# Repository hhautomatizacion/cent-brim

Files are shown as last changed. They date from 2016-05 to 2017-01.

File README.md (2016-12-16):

<br/>
<p align="center">
  
</p>
<br/>

# cent-brim

## Fecha
* 2004

## Descripcion del proyecto
* Modificacion de centrifuga brim para trabajar con motor electrico en lugar de motor hidraulico.

## Herramientas utilizadas
* Ninguna

## Modelos de PLC, etc.
* Variador yaskawa

## Autores
* <a href="http://www.github.com/pedrohermon">pedrohermon</a> 
* <a href="http://www.github.com/genarohh">genarohh</a> 

## Comentarios
* Ninguno

## Contenido
* Carpeta de Diagramas
	* Diagramas del proyecto
		* Diagramas electricos
		* Diagramas de bloques
		* Dibujos
* Carpeta de Documentos
	* Documentos pensados para el usuario final
		* Manuales de usuario
		* Manuales de programacion
* Carpeta de Fotos
	* Fotos del proyecto antes, durante y despues del desarrollo del mismo
		* Fotos
		* Capturas de pantalla
* Carpeta de Historial
	* Documentacion del desarrollo del proyecto
		* Hojas de datos de componentes
		* Manuales de usuario de componentes
		* Documentacion de funciones, herramientas
* Carpeta de Programas
	* Programas de Computadora, PLC, etc. 
		* Codigos fuente
		* Iconos, imagenes usados en los programas
		* Archivos de configuracion de los programas
		* Programas compilados
* Carpeta de Pruebas
	* Pruebas preliminares del proyecto
		* Programas incompletos, o secciones de programas
		* Capturas de comunicacion
		* Modelos de componentes que se hayan probado

---
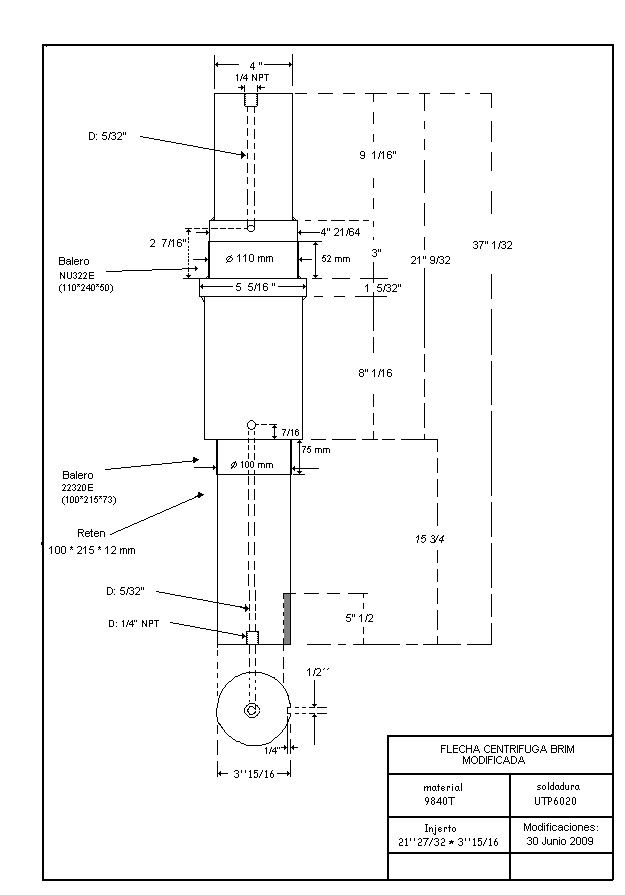
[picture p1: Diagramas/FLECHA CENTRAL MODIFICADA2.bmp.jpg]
FLECHA CENTRAL MODIFICADA2.bmp.jpg

---
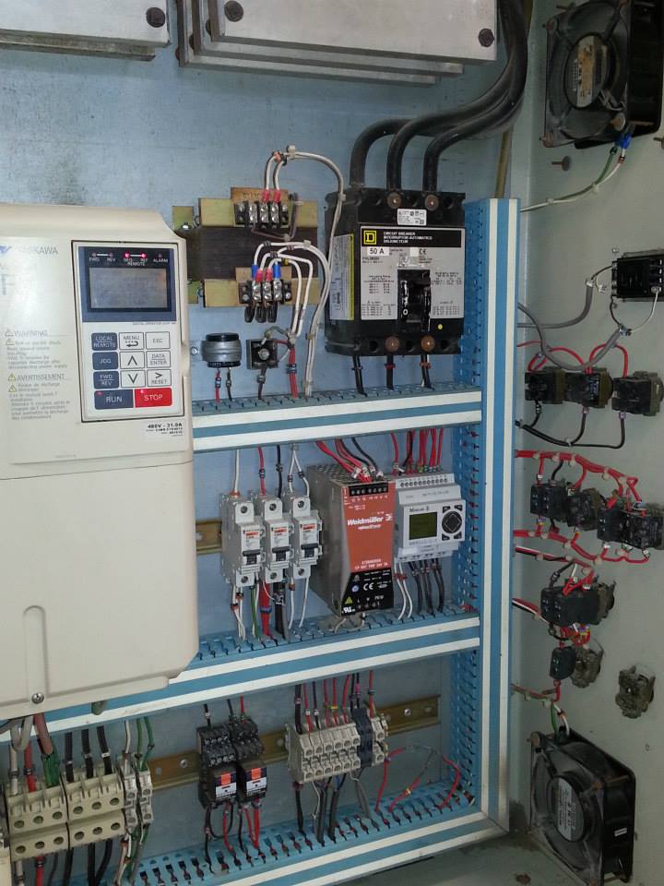
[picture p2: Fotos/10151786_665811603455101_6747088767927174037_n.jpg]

---
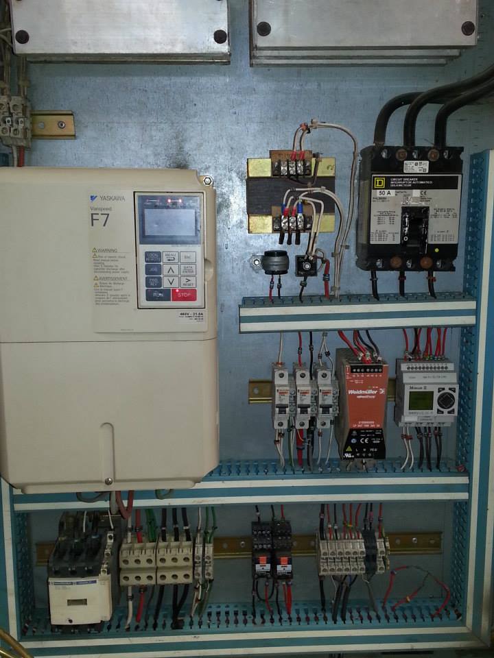
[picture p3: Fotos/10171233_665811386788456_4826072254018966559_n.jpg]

---

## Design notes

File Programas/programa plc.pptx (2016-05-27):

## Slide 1

PROGRAMA DE PLC EASY DE CENTRIFUGA BRIM

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
NOTA: La salida Q1 se conecta al cable no. 22 y 23
La salida Q2 se conecta al cable no. 15 y 71
La salida Q3 se conecta al cable no. 15 y 72
La salida Q4 se conecta al cable no. 15 y 73
VEASE EL DIAGRAMA DE CONTROL

M6

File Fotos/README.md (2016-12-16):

<br/>
<p align="center">
  
</p>
<br/>

# Carpeta de Fotos

## Fotos del proyecto antes, durante y despues del desarrollo del mismo

* Fotos

* Capturas de pantalla

---

---

---

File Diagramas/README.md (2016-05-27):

<br/>
<p align="center">
  
</p>
<br/>

# Carpeta de Diagramas

## Diagramas del proyecto

* Diagramas electricos

* Diagramas de bloques

* Dibujos

---
FLECHA CENTRAL MODIFICADA2.bmp.jpg
---

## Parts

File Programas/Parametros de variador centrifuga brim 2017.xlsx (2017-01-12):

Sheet: Param Cent F7
PARAMETROS PARA VARIADOR DE VELOCIDAD YASKAWA.
MODELO: CIMR-F7U4015
APLICACCION: CENTRIFUGA BRIM
NOTAS:
Para programar, situarse en el menu ( programacion ) y seguir estos pasos!
Opcional, ajustar idioma parametro A1-00 ( Selección de idioma )
Si el equipo es nuevo, aplicar parametros de la siguiente lista, ecepto parametro A1-03 ( Inicializar parametros ).
Si el equipo es usado, Aplicar el parametro A1-03 ( Inicializar parametros ) con la opcion 2220 ( Inicializar en 2 hilos )
Despues ajustar parametros de la siguiente lista, ecepto parametro A1-03 ( Inicializar parametros ).
Codigo | Descripcion | Valor | Descripcion
Parametro | Parametro | Ajustado | Ajuste
A1-00 | Selección de idioma | 5 | Español
A1-01 | Nivel de programacion | 2 | Nivel avanzado
A1-02 | Seleccion el metrodo de control | 2 | Vector abierto
A1-03 | Inicializar parameros (carga parametros de fabrica ) | 2220 | Dos hilos
B1-01 | Selección frecuencia de referencia | 0 | Por operador
C1-01 | Tiempo de aceleracion 1 | 230 | Segundos
C1-02 | Tiempo de desaceleracion 1 | 240 | Segundos
D1-01 | Frecuencia de referencia 1 | 27 | Hertz
D1-03 | Frecuencia de referencia 3 | 55 | Hertz
E1-01 | Voltaje de entrada a inversor | 440 | Volts AC
E1-05 | Voltaje maximo de salida | 440 | Volts AC
E1-08 | Tensión de la frecuencia de salida media | 24.2 | Volts AC
E1-10 | Tensión de la frecuencia de salida mínima | 4.4 | Volts AC
E1-13 | Voltaje base | 440 | Volts AC
E2-01 | Amperes de placa de motor | 19.5 | Amperes
E2-02 | Deslizamiento nominal del motor | 0.81 | Hertz
E2-03 | Amperes de motor sin carga | 8.6 | Amperes
E2-05 | Resistencia linia a linia de motor | 0.76 | Ohms
E2-06 | Inductancia de fuga del motor | 23.6 | Porcentaje
E2-07 | Coeficiente de saturación con núcleo de hierro 1 | 0.43 | Porcentaje
E2-08 | Coeficiente de saturación con núcleo de hierro 2 | 0.68 | Porcentaje
E2-11 | Potencia de motor | 11.19 | Kilowatts
E2-12 | Coeficiente de saturación con núcleo de hierro 3 | 1.6 | Porcentaje
H1-03 | Selección de funcion de terminal S5 | 4 | Referencia de multivelocidad 2
H1-04 | Selección de funcion de terminal S6 | 3 | Referencia de multivelocidad 3
H6-07 | Escala del monitor del tren de pulsos | 570 | Hertz
L1-01 | Selección de protección contra sobrecarga motor | 2 | Hertz
L3-04 | Selección prevencion de bloqueo durante la desaceleracion | 0 | Desactivada
L8-05 | Selección de protección contra pérdida de fase de entrada | 0 | Segundos
L8-09 | Selección de detección de falla de tierra en la salida | 0 | Desactivada
L8-10 | Selección de operación del ventilador de refrigeracion | 1 | Siempre
L8-12 | Configuración de la temperatura ambiente | 55 | Grados centigrados
 |  |  | 2017-01-01

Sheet: Param Cent A1000
PARAMETROS PARA VARIADOR DE VELOCIDAD YASKAWA.
MODELO: CIMR-AU4A0044FAA
APLICACCION: CENTRIFUGA BRIM
NOTAS:
Para programar, situarse en el menu ( programacion ) y seguir estos pasos!
Opcional, ajustar idioma parametro A1-00 ( Selección de idioma )
Si el equipo es nuevo, aplicar parametros de la siguiente lista, ecepto parametro A1-03 ( Inicializar parametros ).
Si el equipo es usado, Aplicar el parametro A1-03 ( Inicializar parametros ) con la opcion 2220 ( Inicializar en 2 hilos )
Despues ajustar parametros de la siguiente lista, ecepto parametro A1-03 ( Inicializar parametros ).
Codigo | Descripcion | Valor | Descripcion
Parametro | Parametro | Ajustado | Ajuste
A1-00 | Selección de idioma | 5 | Español
A1-01 | Nivel de programacion | 2 | Nivel avanzado
A1-02 | Seleccion el metrodo de control | 2 | Vector abierto
A1-03 | Inicializar parameros (carga parametros de fabrica ) | 2220 | Dos hilos
B1-01 | Selección frecuencia de referencia | 0 | Por operador
C1-01 | Tiempo de aceleracion 1 | 230 | Segundos
C1-02 | Tiempo de desaceleracion 1 | 270 | Segundos
D1-01 | Frecuencia de referencia 1 | 27 | Hertz
D1-03 | Frecuencia de referencia 3 | 55 | Hertz
E1-01 | Voltaje de entrada a inversor | 440 | Volts AC
E1-04 | Frecuencia maxima de salida | 80 | Hertz
E1-05 | Voltaje maximo | 440 | Volts AC
E1-13 | Voltaje base | 440 | Volts AC
E2-01 | Amperes de placa de motor | 19.5 | Amperes
E2-02 | Deslizamiento nominal del motor | 0.81 | Hertz
E2-03 | Amperes de motor sin carga | 8.6 | Amperes
E2-05 | Resistencia linia a linia de motor | 0.76 | Ohms
E2-11 | Potencia de motor | 11.19 | Kilowatts
H1-05 | Selección de funcion de terminal S5 | 4 | Referencia de multivelocidad 2
H1-06 | Selección de funcion de terminal S6 | 5 | Referencia de multivelocidad 3
H6-07 | Escala del monitor del tren de pulsos | 570 | Hertz
L3-01 | Selección prevencion de bloqueo durante la aceleracion | 0 | Desactivada
L3-04 | Selección prevencion de bloqueo durante la desaceleracion | 0 | Desactivada
L3-24 | Tiempo de aceleración del motor para calcular la inercia | 0.265 | Segundos
L8-10 | Selección de operación del ventilador de refrigeracion | 1 | Siempre
 |  |  | 2017-01-01

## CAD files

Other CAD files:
Diagramas/Diagrama Centrifuga Brim 2017.dwg
Diagramas/flecha motor 15 hp.dwg
Diagramas/ALTURA DE PIERNA1.dwg
Diagramas/Buje de centrifuga mod.dwg
Diagramas/FLECHA DE PIERNA DE CENTRIFUGA.dwg
Diagramas/Amortiguador Original.dwg
Diagramas/CAJA DE PIERNA.dwg

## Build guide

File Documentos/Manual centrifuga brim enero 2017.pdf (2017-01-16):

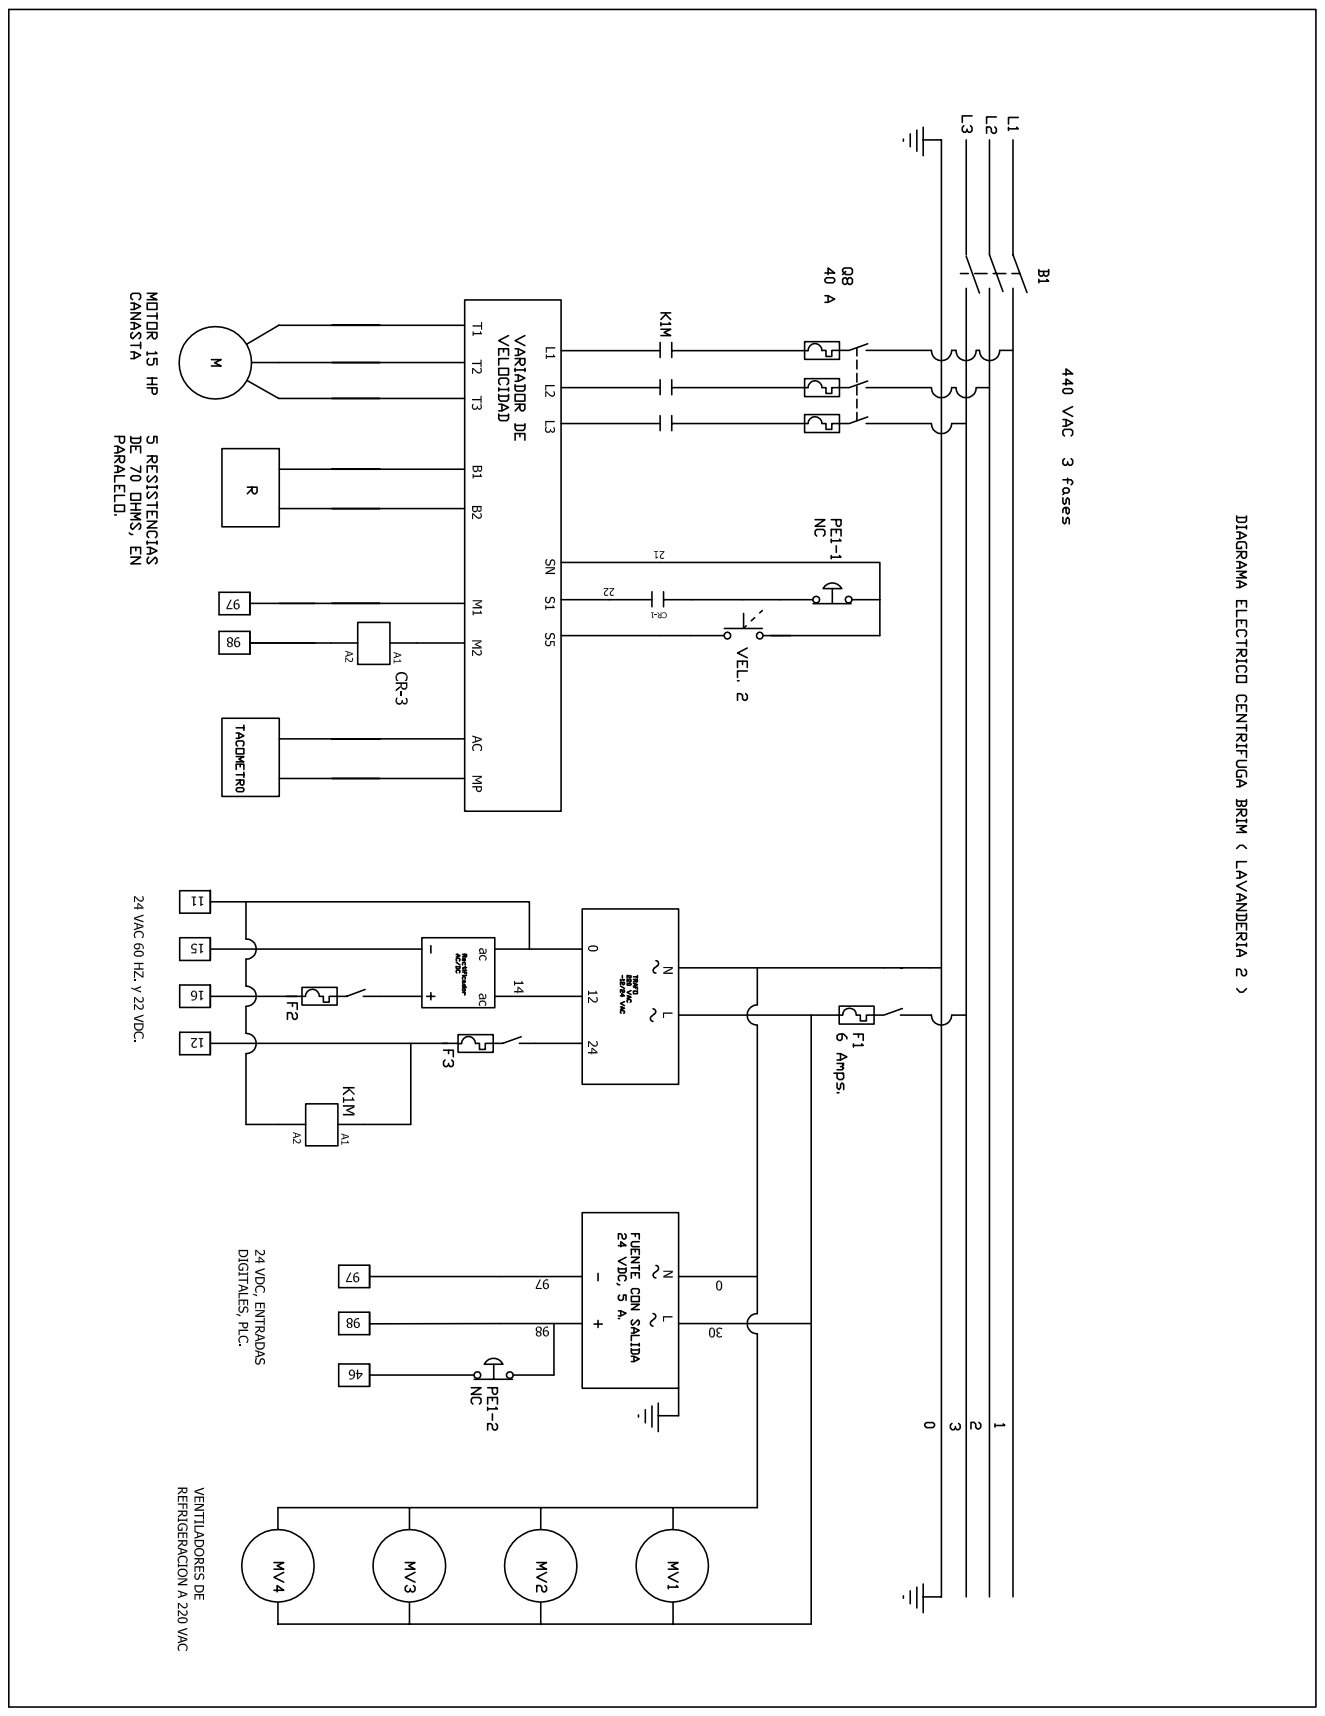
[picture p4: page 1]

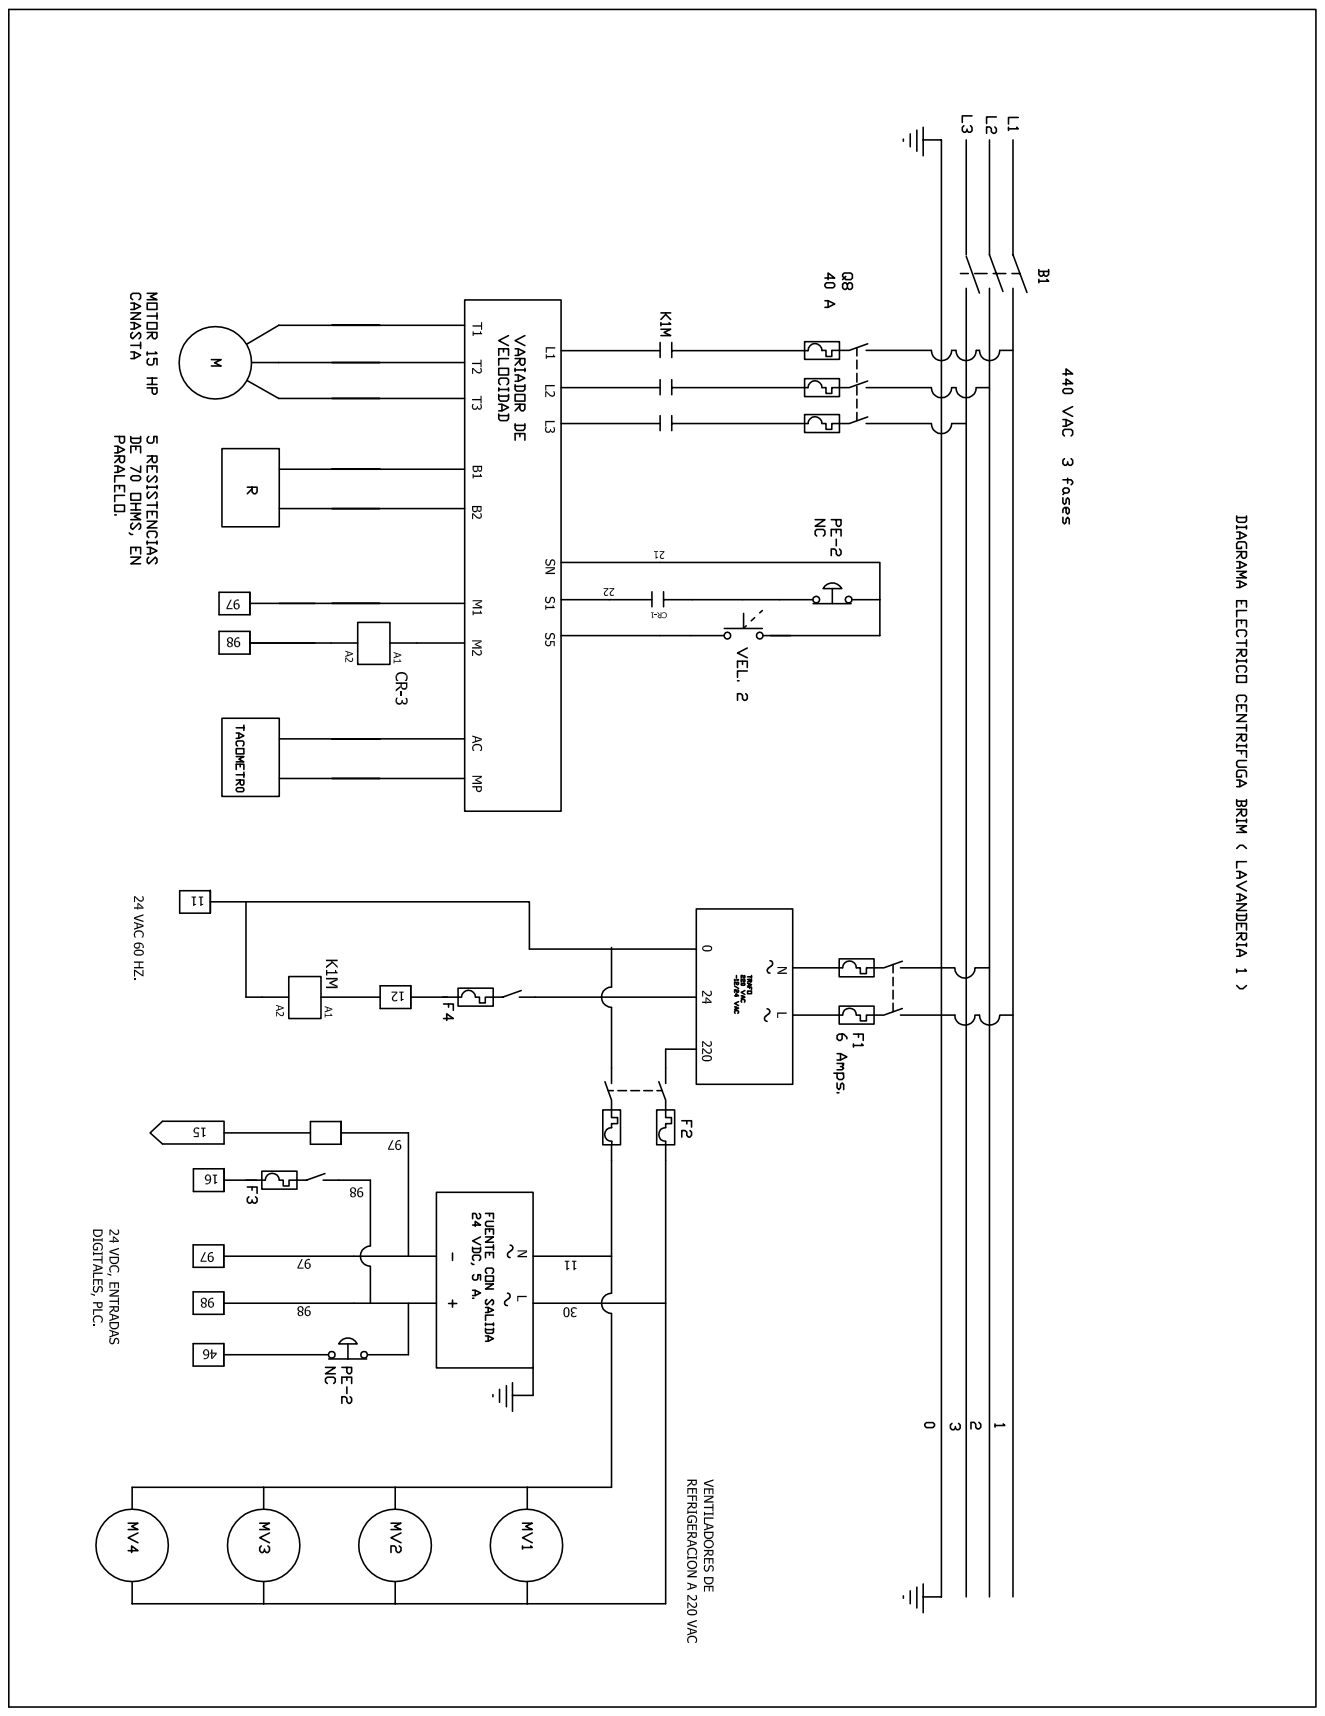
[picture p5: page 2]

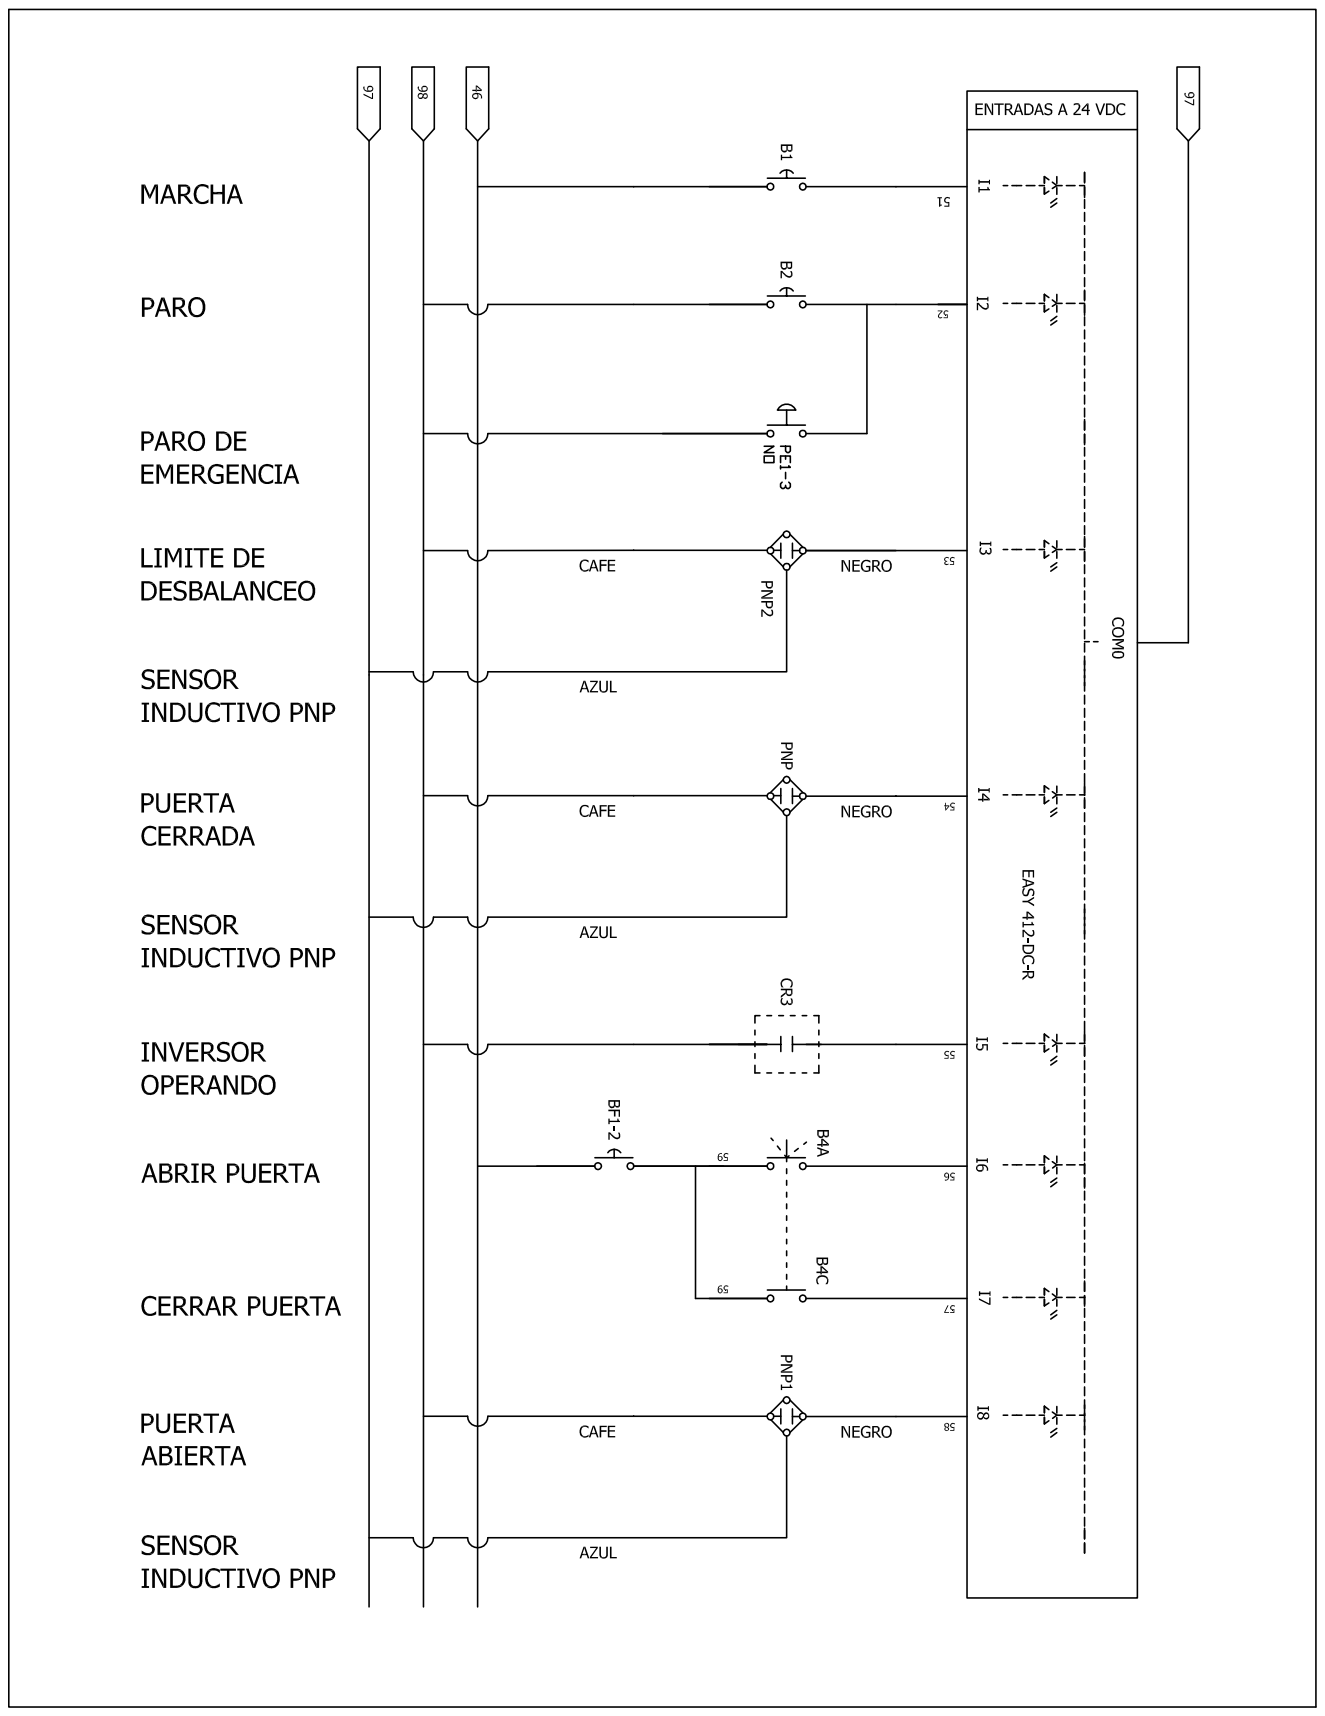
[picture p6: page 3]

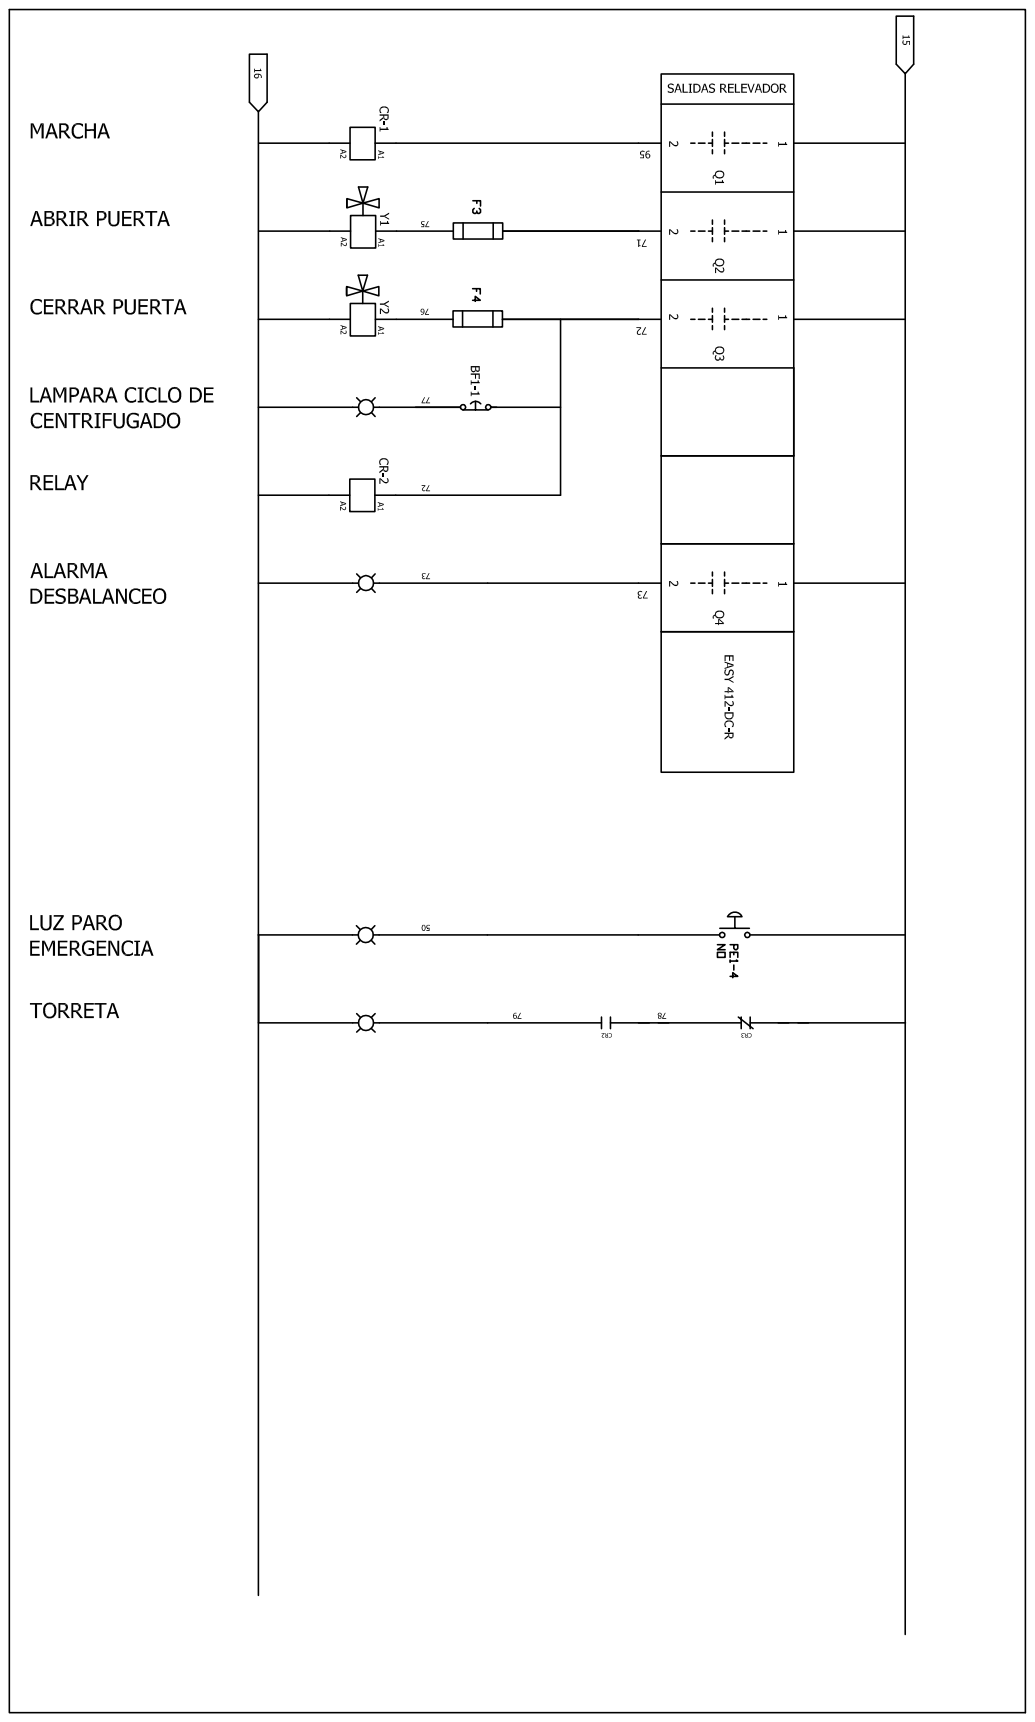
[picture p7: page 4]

### PROGRAMA DE PLC EASY DE CENTRIFUGA BRIM CLAVE DE ACCESO PLC: 0846

M2---M6---I4---{M1 | ;Subrutina de seguridad puerta cerrada.
M1---I1---M8---{M7 | ;subrutina de marcha
--------M7

## M7---M2---------{TT1

## I5-----I3-----I5---{M2 ;subrutina de desbalanceo y reset

M2-----------I2--

## M7-----------------{TT2

M3--
M2---------I6------{M3 | ;subrutina de seguridad, mantener puerta cerrada
M7-- | durante operación.
I5------I6----T2—{M6 | ;subrutina de finalización de ciclo.
M6

## M1---I2-------I5---{M4 ;subrutina de paro y paro de emergencia

M4-

## M7---I4-----M2---{M5

## M5---M4----T1----{Q1 ;subrutina para salida 1, activación de variador

M3

## ---------------{Q3 ;subrutina para salida 3, cerrar puerta

I7

M2-------------------{Q4 | ;subrutina para salida 4, alarma de desbalanceo
I6-----M2----M7---{Q2 | ;subrutina para salida 2, abrir puerta

## I8------I7-----Q1—

## I5------I4------------{M8

M8—

PARAMETROS TEMPORIZADOR 1: 6 MINUTOS, 38 SEGUNDOS.

X 00:00

M: S | 06:38
TRG | T1

## RES

PARAMETROS TEMPORIZADOR 2: 5 SEGUNDOS.

X----- | 00:00
M: S | 00:05
TRG | T2

## RES

### ENERO 2017

PARAMETROS PARA VARIADOR DE VELOCIDAD YASKAWA.

### MODELO: CIMR-F7U4015 APLICACCION: CENTRIFUGA BRIM

### NOTAS:

Para programar, situarse en el menu ( programacion ) y seguir estos pasos!
Opcional, ajustar idioma parametro A1-00 ( Selección de idioma )
Si el equipo es nuevo, aplicar parametros de la siguiente lista, ecepto parametro A1-03 ( Inicializar parametros ).
Si el equipo es usado, Aplicar el parametro A1-03 ( Inicializar parametros ) con la opcion 2220 ( Inicializar en 2 hilos ) Despues ajustar parametros de la siguiente lista, ecepto parametro A1-03 ( Inicializar parametros ).
Codigo | Descripcion | Valor | Descripcion
Parametro | Parametro | Ajustado | Ajuste
A1-00 | Selección de idioma | 5 | Español
A1-01 | Nivel de programacion | 2 | Nivel avanzado
A1-02 | Seleccion el metrodo de control | 2 | Vector abierto
A1-03 | Inicializar parameros (carga parametros de fabrica ) | 2220 | Dos hilos
B1-01 | Selección frecuencia de referencia | 0 | Por operador
C1-01 | Tiempo de aceleracion 1 | 230 | Segundos
C1-02 | Tiempo de desaceleracion 1 | 240 | Segundos
D1-01 | Frecuencia de referencia 1 | 27 | Hertz
D1-03 | Frecuencia de referencia 3 | 55 | Hertz
E1-01 | Voltaje de entrada a inversor | 440 | Volts AC
E1-05 | Voltaje maximo de salida | 440 | Volts AC
E1-08 | Tensión de la frecuencia de salida media | 24.2 | Volts AC
E1-10 | Tensión de la frecuencia de salida mínima | 4.4 | Volts AC
E1-13 | Voltaje base | 440 | Volts AC
E2-01 | Amperes de placa de motor | 19.5 | Amperes
E2-02 | Deslizamiento nominal del motor | 0.81 | Hertz
E2-03 | Amperes de motor sin carga | 8.6 | Amperes
E2-05 | Resistencia linia a linia de motor | 0.76 | Ohms
E2-06 | Inductancia de fuga del motor | 23.6 | Porcentaje
E2-07 | Coeficiente de saturación con núcleo de hierro 1 | 0.43 | Porcentaje
E2-08 | Coeficiente de saturación con núcleo de hierro 2 | 0.68 | Porcentaje
E2-11 | Potencia de motor | 11.19 | Kilowatts
E2-12 | Coeficiente de saturación con núcleo de hierro 3 | 1.6 | Porcentaje
H1-03 | Selección de funcion de terminal S5 | 4 | Referencia de multivelocidad 2
H1-04 | Selección de funcion de terminal S6 | 3 | Referencia de multivelocidad 3
H6-07 | Escala del monitor del tren de pulsos | 570 | Hertz
L1-01 | Selección de protección contra sobrecarga motor | 2 | Hertz
L3-04 | Selección prevencion de bloqueo durante la desaceleracion | 0 | Desactivada
L8-05 | Selección de protección contra pérdida de fase de entrada | 0 | Segundos
L8-09 | Selección de detección de falla de tierra en la salida | 0 | Desactivada
L8-10 | Selección de operación del ventilador de refrigeracion | 1 | Siempre
L8-12 | Configuración de la temperatura ambiente | 55 | Grados centigrados

ene-17

PARAMETROS PARA VARIADOR DE VELOCIDAD YASKAWA.

### MODELO: CIMR-AU4A0044FAA APLICACCION: CENTRIFUGA BRIM

### NOTAS:

Para programar, situarse en el menu ( programacion ) y seguir estos pasos!
Opcional, ajustar idioma parametro A1-00 ( Selección de idioma )
Si el equipo es nuevo, aplicar parametros de la siguiente lista, ecepto parametro A1-03 ( Inicializar parametros ).
Si el equipo es usado, Aplicar el parametro A1-03 ( Inicializar parametros ) con la opcion 2220 ( Inicializar en 2 hilos ) Despues ajustar parametros de la siguiente lista, ecepto parametro A1-03 ( Inicializar parametros ).
Codigo | Descripcion | Valor | Descripcion
Parametro | Parametro | Ajustado | Ajuste
A1-00 | Selección de idioma | 5 | Español
A1-01 | Nivel de programacion | 2 | Nivel avanzado
A1-02 | Seleccion el metrodo de control | 2 | Vector abierto
A1-03 | Inicializar parameros (carga parametros de fabrica ) | 2220 | Dos hilos
B1-01 | Selección frecuencia de referencia | 0 | Por operador
C1-01 | Tiempo de aceleracion 1 | 230 | Segundos
C1-02 | Tiempo de desaceleracion 1 | 270 | Segundos
D1-01 | Frecuencia de referencia 1 | 27 | Hertz
D1-03 | Frecuencia de referencia 3 | 55 | Hertz
E1-01 | Voltaje de entrada a inversor | 440 | Volts AC
E1-04 | Frecuencia maxima de salida | 80 | Hertz
E1-05 | Voltaje maximo | 440 | Volts AC
E1-13 | Voltaje base | 440 | Volts AC
E2-01 | Amperes de placa de motor | 19.5 | Amperes
E2-02 | Deslizamiento nominal del motor | 0.81 | Hertz
E2-03 | Amperes de motor sin carga | 8.6 | Amperes
E2-05 | Resistencia linia a linia de motor | 0.76 | Ohms
E2-11 | Potencia de motor | 11.19 | Kilowatts
H1-05 | Selección de funcion de terminal S5 | 4 | Referencia de multivelocidad 2
H1-06 | Selección de funcion de terminal S6 | 5 | Referencia de multivelocidad 3
H6-07 | Escala del monitor del tren de pulsos | 570 | Hertz
L3-01 | Selección prevencion de bloqueo durante la aceleracion | 0 | Desactivada
L3-04 | Selección prevencion de bloqueo durante la desaceleracion | 0 | Desactivada
L3-24 | Tiempo de aceleración del motor para calcular la inercia | 0.265 | Segundos
L8-10 | Selección de operación del ventilador de refrigeracion | 1 | Siempre

ene-17

# DIAGRAMA NEUMATICO DE CENTRIFUGA BRIM

## Enero 2017

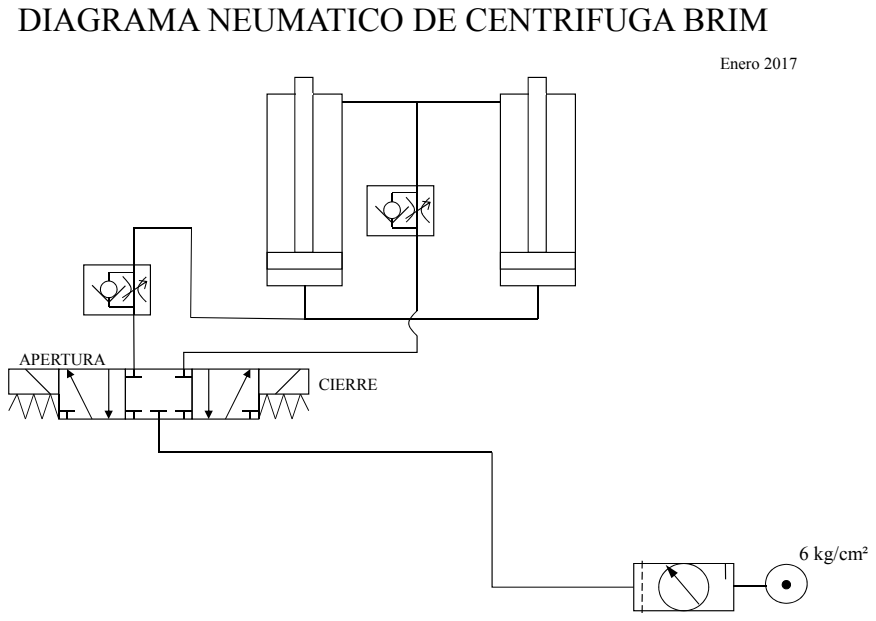
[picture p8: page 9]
APERTURA; CIERRE; 6 kg/cm²

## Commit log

2016-05-27 Commit inicial
    [ALTURA DE PIERNA1.dwg, Amortiguador Original.dwg, Buje de centrifuga mod.dwg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]
2016-12-05 Se agrega manual de usuario de PLC.
2016-12-16 Se actualiza documentacion
    [ENTRADAS Y SALIDAS PLC.xlsx]
2017-01-16 modificacion del programa.
    [Diagrama Centrifuga Brim 2017.dwg]
2017-01-16 prueba de subir doc
2017-01-16 borrado
    se borra documento de prueba
